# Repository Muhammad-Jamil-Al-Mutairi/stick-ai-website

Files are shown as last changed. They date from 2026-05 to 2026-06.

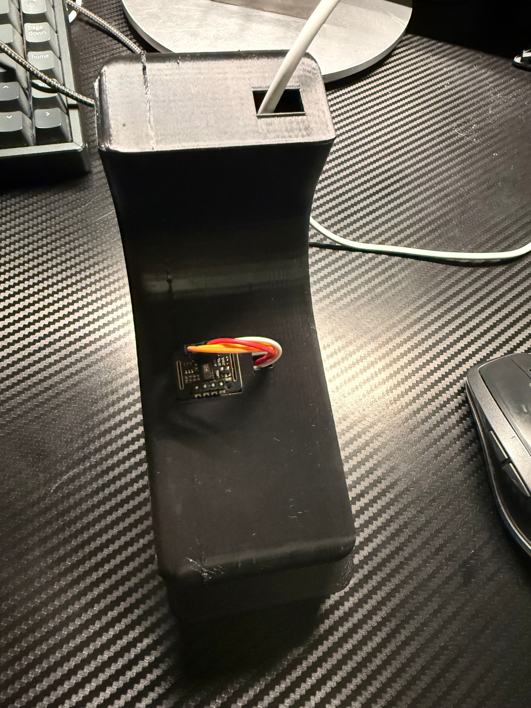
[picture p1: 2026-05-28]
Project_photos/2_IMG.jpg

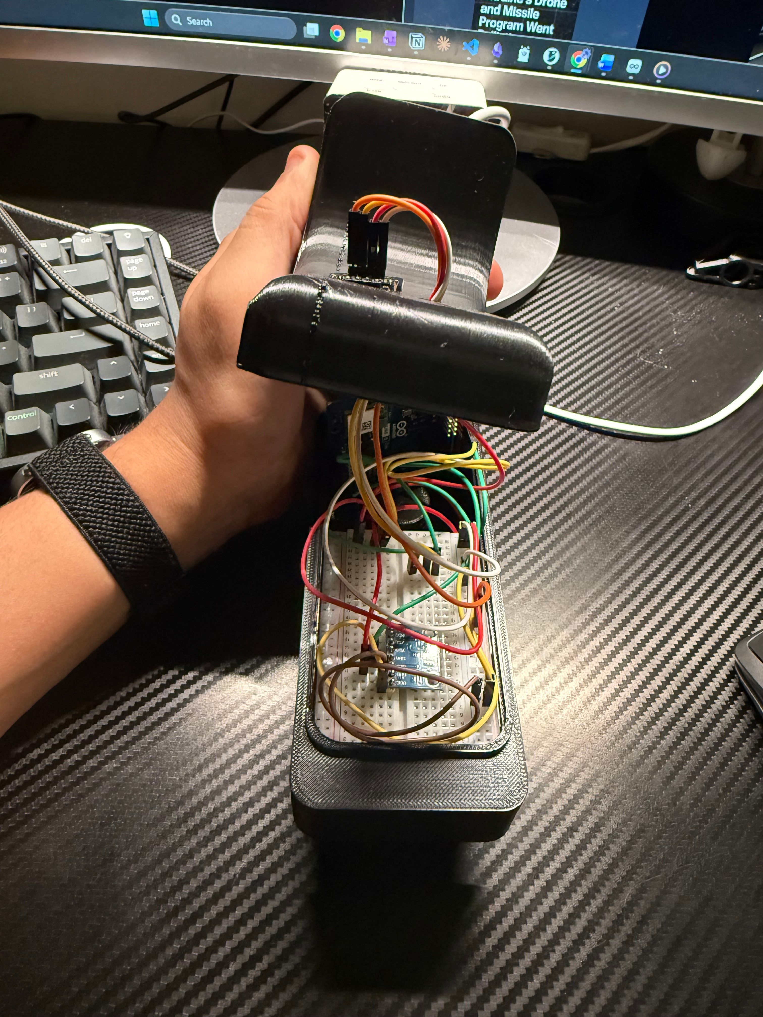
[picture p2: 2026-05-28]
Project_photos/1_IMG.jpg

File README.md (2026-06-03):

https://github.com/user-attachments/assets/0914f391-97e5-4d44-b6d7-df0a50997295

# Stick.AI: Predictive Mobility & Fall Detection System 🦯🧠





The AI Stick is a comprehensive Internet of Things (IoT) medical device and telemetry dashboard. It transforms a standard walking stick into a smart mobility aid capable of real-time pulse oximetry monitoring and AI-driven emergency fall detection. 

By bridging bare-metal C++ sensor reading with a cloud-based Linux Python container, this project successfully streams complex biomechanical data to a Qualcomm Snapdragon-powered Neural Network for real-time classification, ultimately broadcasting the results to a live Firebase web dashboard.

---

## 📂 Repository Structure

This repository is organized by architectural function:

* 📁 **`3D_models/`** - Onshape `.STL` and `.STEP` files for the custom printed handle and enclosures.
* 📁 **`arduino_edge_node/`** - C++ firmware for the Arduino UNO Q (I2C sensor polling and bridging).
* 📁 **`hardware_schematic/`** - Circuit diagrams, Fritzing layouts, and electrical documentation.
* 📁 **`project_photos/`** - Physical prototype images and live demonstration media.
* 📁 **`python_cloud_bridge/`** - The `main.py` state machine and the `aarch64` TensorFlow Lite AI model.
* 📁 **`web_dashboard/`** - HTML, CSS, and JS files powering the live Firebase telemetry dashboard.

---

## 🏗️ System Architecture

This project operates across three major engineering domains:

1. **Bare-Metal Edge Hardware:** An Arduino UNO Q acts as the physical edge node, utilizing heavily optimized timing loops to read an MPU-6050 (IMU) and a MAX30102 (Pulse Oximeter). It processes heartbeat peak-detection locally and buffers accelerometer data at exactly 25Hz.
2. **Cloud AI Bridge:** A custom Python container intercepts the hardware telemetry. It runs a custom-trained, quantized Edge Impulse classification model locally on the Qualcomm chip, bypassing standard latency bottlenecks.
3. **Real-Time Telemetry Dashboard:** The Python bridge patches inference results (e.g., `✅ Walking Safely`, `🚨 FALL DETECTED`) and vital signs to a Firebase Realtime Database. A sleek web dashboard listens to this database to render live, animated charts and status badges remotely.

---

## 🔌 Circuit Schematic & Hardware

The electrical system requires precise I2C communication between the sensors and the microcontroller. 


**Core Components:**
* **Microcontroller:** Arduino UNO Q 
* **IMU:** GY-521 (MPU-6050 6-DoF Accelerometer & Gyroscope)
* **Vitals:** RCWL-0530 (MAX30102 Pulse Oximetry & Heart Rate)
* **Communication:** I2C Protocol

---

## 🖨️ 3D Design & Enclosure

To make the system physically viable, custom mounts and enclosures were designed in **Onshape**. The mechanical designs focus on ergonomics and secure housing for the I2C wiring, protecting the delicate sensor arrays from impact during a detected fall. The design files were rapidly prototyped and printed using a Creality Ender 3 V3 SE.

* **Interactive CAD:** [View the complete 3D design workspace on Onshape](https://cad.onshape.com/documents/027696098c048843e6e8f9b6/w/f13f1546ddf5b77709304479/e/49368f70d675277c00a1590c)

---

## 🚀 Installation & Usage

### 1. Hardware Setup
Flash the C++ script located in the `arduino_edge_node` folder to your Arduino UNO Q. Ensure the I2C sensors are wired according to the schematic.

### 2. Booting the AI Bridge
Open the Arduino App Lab. Run the `main.py` script located in the `python_cloud_bridge` folder. The script will automatically configure the environment, unlock Linux execution permissions for the `.eim` model, and boot the Neural Network.

### 3. Web Dashboard
The dashboard is currently live via GitHub pages. You can monitor the system telemetry in real-time here: **[Stick.AI Live Dashboard](https://muhammad-jamil-al-mutairi.github.io/stick-ai-website/)**

---
*Engineered by Muhammad Jamil Almutairi — Shaqra University, Department of Computer Engineering*

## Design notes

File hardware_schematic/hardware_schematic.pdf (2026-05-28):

### Hardware Schematic & Wiring Specification

Project: AI stick: Predictive Mobility & Fall Detection System

Lead Engineer: Muhammad Jamil Almutairi

Institution: Shaqra University, Department of Computer Engineering

### 1. System Overview

This document details the electrical wiring and I2C communication pathways for the AI stick hardware node. The system integrates a central microcontroller with dual biomedical and biomechanical sensors to capture real-time human telemetry.

### 2. Component Roster

- Microcontroller: Arduino UNO Q (Qualcomm Snapdragon architecture)
- Biomechanical Sensor (IMU): MPU-6050 (6-DoF Accelerometer & Gyroscope)
- Biomedical Sensor (Pulse Oximetry): MAX30102 (High-Sensitivity SpO2 & Heart Rate)
- Infrastructure: Standard breadboard and jumper wiring

### 3. Wiring Diagrams

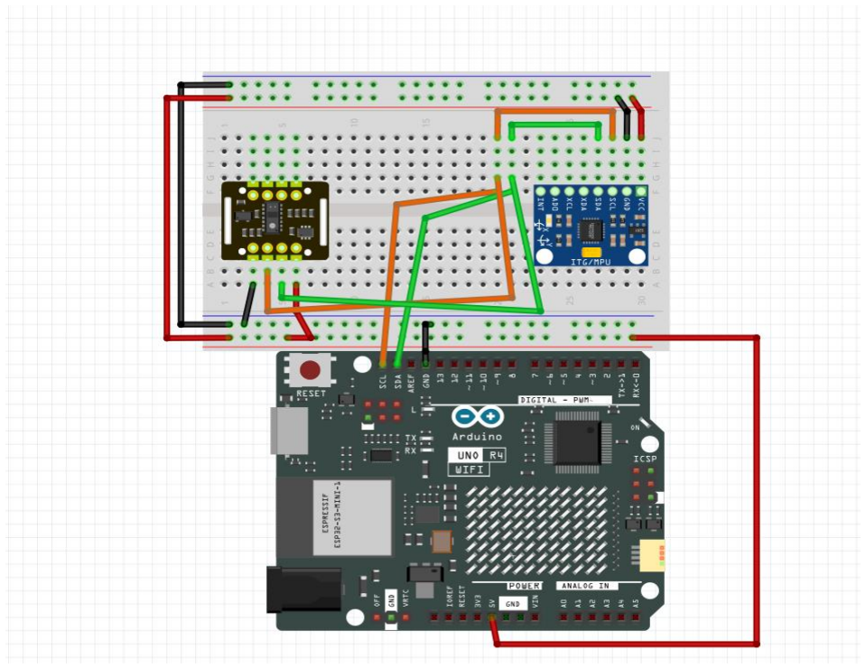
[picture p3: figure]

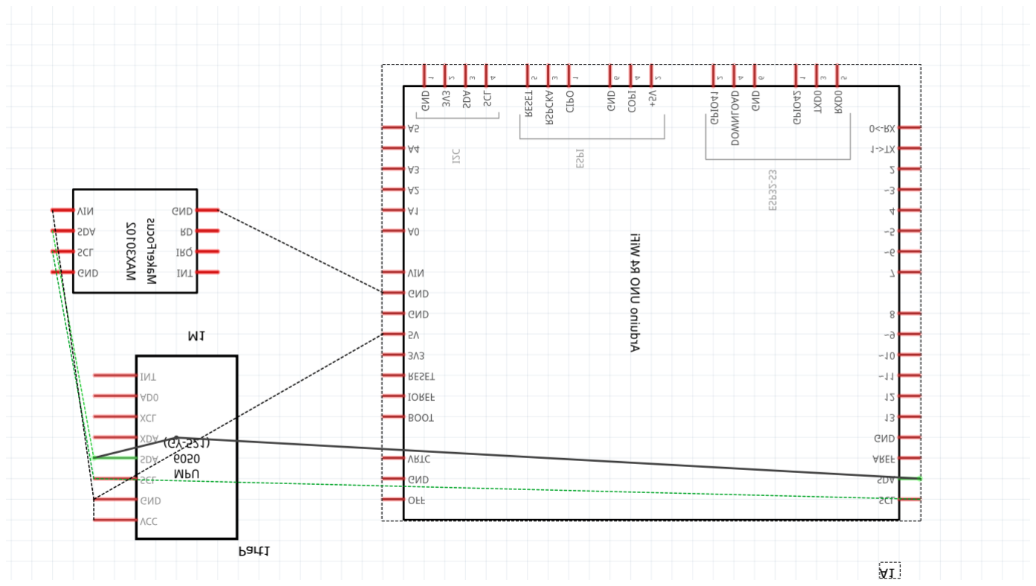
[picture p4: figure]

Important Engineering Note Regarding CAD Diagrams: The Fritzing diagrams above utilize the symbol for the Arduino UNO R4 WiFi as a visual placeholder. The physical deployment of the AI stick utilizes the Arduino UNO Q. Because the UNO Q shares the standard Arduino R3/R4 physical pinout footprint, the electrical pathways, power distribution, and I2C bus connections depicted in these diagrams remain 100% accurate to the physical build.

### 4. Pin Connection Mapping

The system utilizes the I2C (Inter-Integrated Circuit) protocol to allow both sensors to communicate with the microcontroller over the same two data lines.

Arduino UNO Q Pin | MPU-6050 Pin | MAX30102 Pin | Function Description
5V | VCC | VIN | Main logic power supply
GND | GND | GND | Common ground reference
SCL (or Pin A5) | SCL | SCL | I2C Serial Clock Line
SDA (or Pin A4) | SDA | SDA | I2C Serial Data Line

### 5. Power and Communication Architecture

- I2C Bus Sharing: Both the MPU-6050 and the MAX30102 are connected in parallel to the Arduino's SCL and SDA pins. The Arduino distinguishes between the two sensors in the C++ software using their unique, hardcoded I2C hexadecimal addresses.
- Power Distribution: The 5V pin from the Arduino UNO Q routes to the positive power rail of the breadboard, which then distributes power to the VCC/VIN pins of both breakout boards. Both sensors share a common ground loop back to the microcontroller to prevent voltage floating.

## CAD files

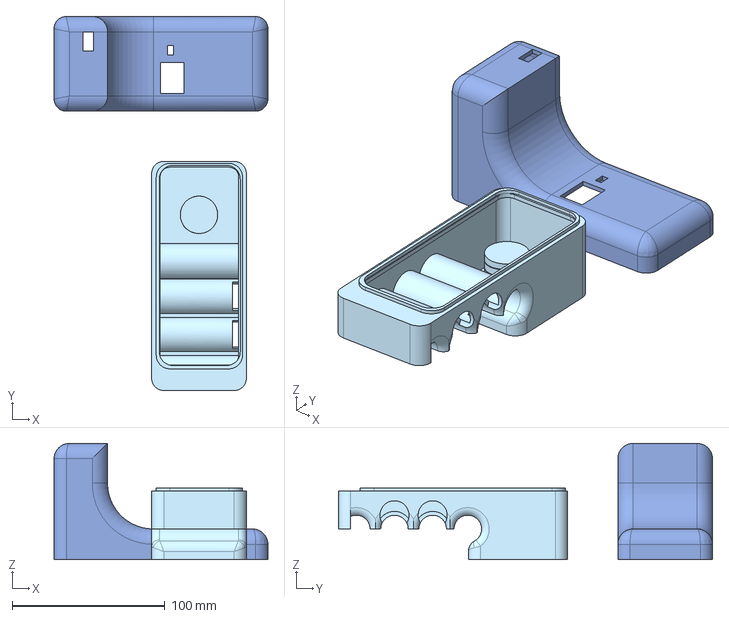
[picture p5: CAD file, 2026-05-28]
3D_models/AI Stick Project.step
140.0 x 244.8 x 76.0 mm

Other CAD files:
3D_models/AI Stick Project.3mf

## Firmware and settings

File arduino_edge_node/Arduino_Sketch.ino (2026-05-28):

include <Arduino_RouterBridge.h>
#include <Wire.h>
#include <Adafruit_MPU6050.h>
#include "MAX30105.h"
#include "heartRate.h" // The built-in peak detection algorithm

Adafruit_MPU6050 mpu;
MAX30105 particleSensor;

unsigned long lastUpdateMillis = 0;
const long UPDATE_INTERVAL = 20; 
int movementSampleCount = 0;

// Heart Rate Math Variables
const byte RATE_SIZE = 4; // Average across 4 beats
byte rates[RATE_SIZE]; 
byte rateSpot = 0;
long lastBeat = 0; 
float beatsPerMinute;
int beatAvg = 0;

void bridgeLog(String message) {
    Bridge.notify("log_data_properly", message);
}

void setup() {
    pinMode(LED_BUILTIN, OUTPUT); 
    Bridge.begin();
    delay(2000); 
    
    bridgeLog("Initializing AI Stick Hardware...");
    Wire.begin(); 

    if (!mpu.begin(0x68, &Wire)) bridgeLog("Error: MPU-6050 not found!");
    else {
        mpu.setAccelerometerRange(MPU6050_RANGE_8_G);
        bridgeLog("MPU-6050 initialized.");
    }

    if (!particleSensor.begin(Wire, I2C_SPEED_STANDARD)) bridgeLog("Error: MAX30102 not found!");
    else {
        particleSensor.setup();
        particleSensor.setPulseAmplitudeRed(0x1F);
        particleSensor.setPulseAmplitudeIR(0x1F);
        bridgeLog("MAX30102 initialized.");
    }
}

void loop() {
    digitalWrite(LED_BUILTIN, (millis() / 500) % 2); 
    unsigned long currentMillis = millis();

    // =========================================================
    // 1. FAST POLLING (Runs constantly to keep Heart Rate accurate)
    // =========================================================
    long irValue = particleSensor.getIR();
    
    // Clear the ghost average if you lift your finger!
    if (irValue < 20000) {
        beatAvg = 0; 
    } 
    
    if (checkForBeat(irValue) == true) {
        long delta = millis() - lastBeat;
        lastBeat = millis();
        beatsPerMinute = 60 / (delta / 1000.0); 
        
        if (beatsPerMinute < 255 && beatsPerMinute > 20) {
            rates[rateSpot++] = (byte)beatsPerMinute;
            rateSpot %= RATE_SIZE;
            beatAvg = 0;
            for (byte x = 0 ; x < RATE_SIZE ; x++) beatAvg += rates[x];
            beatAvg /= RATE_SIZE;
        }
    }
    
    // =========================================================
    // 2. TIMED POLLING (Runs every 20ms for AI IMU Data)
    // =========================================================
    if (currentMillis - lastUpdateMillis >= UPDATE_INTERVAL) {
        lastUpdateMillis = currentMillis;

        sensors_event_t a, g, temp;
        mpu.getEvent(&a, &g, &temp);

        movementSampleCount++;

        // THE FIX: Changed from 10 to 2. 
        // This forces the board to send data every 40ms (25Hz)
        if (movementSampleCount >= 2) { 
            // Send accelerometer data to the Python AI script
            Bridge.notify("record_sensor_movement", a.acceleration.x, a.acceleration.y, a.acceleration.z);
            
            // Send heart rate data to the Python AI script
            bridgeLog("HR_DEBUG:" + String(beatAvg) + "," + String(irValue)); 
            
            movementSampleCount = 0;
        }
    }
}
